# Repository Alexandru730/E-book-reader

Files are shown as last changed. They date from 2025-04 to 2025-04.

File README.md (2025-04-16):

# 📦 ESP32-C6 ePaper Project

Un proiect hardware ce integreaza un modul **ESP32-C6**, un **display e-Paper 7.5"**, alimentare prin **baterie Li-Ion** si conexiuni de testare prin **testpad-uri**. 

---

## 📊 Diagrama bloc

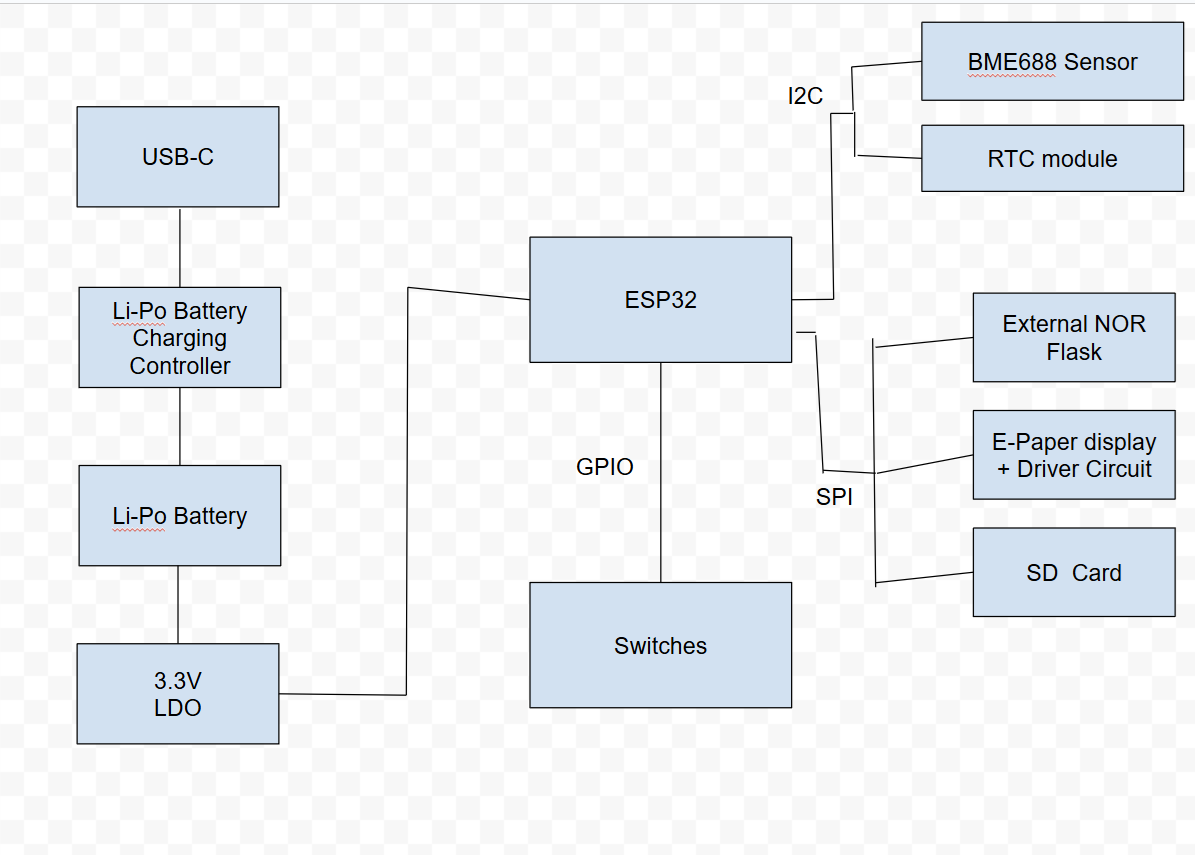
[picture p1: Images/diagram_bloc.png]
Diagrama Bloc


---

## 📦 BOM – Bill of Materials
| Componenta | Achizitie | Datasheet |
|---|---|---|
| PFMF.050.1 | [Cumpara](https://ro.mouser.com/ProductDetail/Schurter/PFMF.050.2?qs=1auRipcfynCums5v1iucSA%3D%3D) | [Datasheet](https://ro.mouser.com/datasheet/2/358/typ_PFMF-1275918.pdf) |
| USB4110-GF-A | [Cumpara](https://ro.mouser.com/ProductDetail/GCT/USB4110-GF-A?qs=KUoIvG%2F9IlYiZvIXQjyJeA%3D%3D) | [Datasheet](https://ro.mouser.com/datasheet/2/837/GCT_USB4110_Product_Drawing___20k_cycles-3455479.pdf) |
| USBLC6-2SC6Y | [Cumpara](https://ro.mouser.com/ProductDetail/STMicroelectronics/USBLC6-2SC6Y?qs=gNDSiZmRJS%2FOgDexvXkdow%3D%3D) | [Datasheet](https://ro.mouser.com/datasheet/2/389/usblc6_2sc6y-1852505.pdf) |
| SD0805S020S1R0 | [Cumpara](https://ro.mouser.com/ProductDetail/KYOCERA-AVX/SD0805S020S1R0?qs=jCA%252BPfw4LHbpkAoSnwrdjw%3D%3D) | [Datasheet](https://ro.mouser.com/datasheet/2/40/schottky-3165252.pdf) |
| DMG2305UX-7 | [Cumpara](https://ro.mouser.com/ProductDetail/Diodes-Incorporated/DMG2305UX-7?qs=L1DZKBg7t5F%2FNBHrjfxC%252Bg%3D%3D) | [Datasheet](https://www.diodes.com/assets/Datasheets/DMG2305UX.pdf) |
| XC6220A331MR-G | [Cumpara](https://ro.mouser.com/ProductDetail/Torex-Semiconductor/XC6220A331MR-G?qs=AsjdqWjXhJ8ZSWznL1J0gg%3D%3D) | [Datasheet](https://ro.mouser.com/datasheet/2/760/xc6220-3371556.pdf) |
| Condensator 100 uF TANT | [Cumpara](https://ro.mouser.com/ProductDetail/KYOCERA-AVX/TAJW107M010RNJ?qs=Wtp%252Bf%2FAeVqIH8v1VxV%252B1Rg%3D%3D) | [Datasheet](https://ro.mouser.com/datasheet/2/40/TAJ-3165264.pdf) |
| 112A-TAAR-R03_ATTEND | [Cumpara](https://www.digikey.ro/en/products/detail/attend-technology/112A-TAAR-R03/17633923) | [Datasheet](https://www.attend.com.tw/data/download/file/112A-TAAR-R03_Spec.pdf) |
| ESP32-C6-WROOM-1-N8 | [Cumpara](https://ro.mouser.com/ProductDetail/Espressif-Systems/ESP32-C6-WROOM-1-N8?qs=8Wlm6%252BaMh8ST02Gmwp74cw%3D%3D) | [Datasheet](https://ro.mouser.com/datasheet/2/891/Espressif_ESP32_C6_WROOM_1__Datasheet_V0_1_PRELIMI-3239987.pdf) |
| MCP73831 | [Cumpara](https://ro.mouser.com/ProductDetail/Microchip-Technology/MCP73831T-2ACI-OT?qs=yUQqVecv4qvbBQBGbHx0Mw%3D%3D) | [Datasheet](https://ro.mouser.com/datasheet/2/268/MCP73831_Family_Data_Sheet_DS20001984H-3441711.pdf) |
| CHG_LED | [Cumpara](https://store.comet.srl.ro/Catalogue/Product/40478/) | [Datasheet](https://www.snapeda.com/parts/KP-1608SURCK/Kingbright/datasheet/) |
| SI1308EDL-T1-GE3 | [Cumpara](https://ro.mouser.com/ProductDetail/Vishay-Semiconductors/SI1308EDL-T1-GE3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) | [Datasheet](https://www.vishay.com/doc?63399) |
| MBR0530 | [Cumpara](https://ro.mouser.com/ProductDetail/Micro-Commercial-Components-MCC/MBR0530-T?qs=9VyI4qLX4NTSXkb9ynzJnA%3D%3D) | [Datasheet](https://ro.mouser.com/datasheet/2/258/mcc_mbr0520~mbr0560sod123-1179695.pdf) |
| Bobina | [Cumpara](https://ro.mouser.com/ProductDetail/Wurth-Elektronik/744043680?qs=PGXP4M47uW6VkZq%252BkzjrHA%3D%3D) | [Datasheet](https://www.we-online.com/components/products/datasheet/744043680.pdf) |
| FH34SRJ-24S-0.5SH_99_ | [Cumpara](https://ro.mouser.com/ProductDetail/Hirose-Connector/FH34SRJ-24S-0.5SH99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) | [Datasheet](https://ro.mouser.com/datasheet/2/185/FH34SRJ_24S_0_5SH_99__CL0580_1255_6_99_2DDrawing_0-1615044.pdf) |
| BME688 | [Cumpara](https://ro.mouser.com/ProductDetail/Bosch-Sensortec/BME688?qs=IS%252B4QmGtzzqQoVDscqwx3A%3D%3D) | [Datasheet](https://ro.mouser.com/datasheet/2/783/bst_bme688_fl000-2307034.pdf) |
| BD5229G-TR | [Cumpara](https://ro.mouser.com/ProductDetail/ROHM-Semiconductor/BD5229G-TR?qs=4kLU8WoGk0vvnhrrYwdszw%3D%3D) | [Datasheet](https://fscdn.rohm.com/en/products/databook/datasheet/ic/power/voltage_detector/bd52xxg-e.pdf) |
| Switch | [Cumpara](https://ro.mouser.com/ProductDetail/CK/KMR221GULCLFS?qs=u2NJ%252B70r0goBXaNk7IrU0Q%3D%3D) | [Datasheet](https://www.ckswitches.com/media/1479/kmr2.pdf) |
| MAX17048G+T10 | [Cumpara](https://ro.mouser.com/ProductDetail/Analog-Devices-Maxim-Integrated/MAX17048G%2bT10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) | [Datasheet](https://ro.mouser.com/datasheet/2/609/MAX17048_MAX17049-3469099.pdf) |
| W25Q512JVEIQ | [Cumpara](https://ro.mouser.com/ProductDetail/Winbond/W25Q512JVEIQ?qs=l7cgNqFNU1jw6svr3at6tA%3D%3D) | [Datasheet](https://ro.mouser.com/datasheet/2/949/Winbond_W25Q512JV_Datasheet-3240039.pdf) |
| PGB1010603MR | [Cumpara](https://ro.mouser.com/ProductDetail/Littelfuse/PGB1010603MRHF?qs=KvZd0dN2Zg%2FuIq6icj%252BGKA%3D%3D) | [Datasheet](https://www.littelfuse.com/media?itemid=8a337998-d54d-466b-be4e-dc5bcd1f9321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) |
| QWIIC_RIGHT_ANGLE | [Cumpara](https://ro.mouser.com/ProductDetail/Analog-Devices-Maxim-Integrated/DS3231SN?qs=ffX8NcjNb2RmKAb9wAk9Ug%3D%3D) | [Datasheet](https://ro.mouser.com/datasheet/2/837/GCT_USB4110_Product_Drawing___20k_cycles-3455479.pdf) |
| DS3231SN# | [Cumpara](https://ro.mouser.com/ProductDetail/Analog-Devices-Maxim-Integrated/DS3231SN?qs=ffX8NcjNb2RmKAb9wAk9Ug%3D%3D) | [Datasheet](https://ro.mouser.com/datasheet/2/609/DS3231-3421123.pdf) |
| CPH3225A C10_SUPERCAP | [Cumpara](https://ro.mouser.com/ProductDetail/Seiko-Semiconductors/CPH3225A?qs=3etwrb1wR%252BhUOph6lAO7eg%3D%3D) | [Datasheet](https://ro.mouser.com/datasheet/2/360/Seiko_Instruments_MicroBattery_E_20230330_2024Jan_-3561061.pdf) |
| Condensator 100nF | [Cumpara](https://ro.mouser.com/ProductDetail/KYOCERA-AVX/06033G104ZAT2A?qs=NXubJDmysXJMPmHfVo6Z%252BA%3D%3D) | [Datasheet](https://ro.mouser.com/datasheet/2/40/KGM_Y5V-3223189.pdf) |
| Condensator 4.7uF | [Cumpara](https://ro.mouser.com/ProductDetail/KYOCERA-AVX/0402ZD475MAT2A?qs=NBFAU1oqP4W4U2PCPHI0sg%3D%3D) | [Datasheet](https://ro.mouser.com/datasheet/2/40/cx5r_KGM-3223198.pdf) |
| Condensator 10uF | [Cumpara](https://ro.mouser.com/ProductDetail/Samsung-Electro-Mechanics/CL10A106KQ8NNNL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) | [Datasheet](https://ro.mouser.com/datasheet/2/585/MLCC-1837944.pdf) |
| Condensator 1uF/50V | [Cumpara](https://ro.mouser.com/ProductDetail/KYOCERA-AVX/06035D105MAT2A?qs=k4kUdCzLgS5%252BURKe1SOIeQ%3D%3D) | [Datasheet](https://ro.mouser.com/datasheet/2/40/cx5r_KGM-3223198.pdf) |
| Rezistenta 10K | [Cumpara](https://ro.mouser.com/ProductDetail/Vishay-Beyschlag/MCS0402MD1002BE000?qs=17u8i%2FzlE8%2F9BrAaXkMk1w%3D%3D) | [Datasheet](https://www.vishay.com/doc?28952) |
| Rezistenta 200 | [Cumpara](https://ro.mouser.com/ProductDetail/Vishay-Beyschlag/MCS0402MD2000BE100?qs=3SvaY9RawMJNVte4F12%252BZQ%3D%3D) | [Datasheet](https://www.vishay.com/doc?28952) |
| Rezistenta 100K | [Cumpara](https://ro.mouser.com/ProductDetail/Vishay-Beyschlag/MCT0603PD1003DP500?qs=5aG0NVq1C4wWAn8Ei3OpZA%3D%3D) | [Datasheet](https://www.vishay.com/doc?28916) |
| Rezistenta 2.2 | [Cumpara](https://ro.mouser.com/ProductDetail/SEI-Stackpole/RMCF0402FT2R20?qs=IPgv5n7u5QbBgyl0jwhwsA%3D%3D) | [Datasheet](https://ro.mouser.com/datasheet/2/385/SEI_RMCF_RMCP-3077565.pdf) |
| Rezistenta 5K1 | [Cumpara](https://www.venkel.com/part/TFCR0603-16W-K-5690FT) | [Datasheet](https://ro.mouser.com/datasheet/2/385/SEI_RMCF_RMCP-3077565.pdf) |
| Rezistenta 2K | [Cumpara](https://ro.mouser.com/ProductDetail/Vishay-Beyschlag/MCS04020C2001FE000?qs=wTZ%2FFzl837YG0wIkZJJOwQ%3D%3D) | [Datasheet](https://www.vishay.com/doc?28705) |
| Rezistenta 0.47 | [Cumpara](https://ro.mouser.com/ProductDetail/SEI-Stackpole/CSR0402JKR470?qs=IPgv5n7u5QawIB6nBEt8wA%3D%3D) | [Datasheet](https://ro.mouser.com/datasheet/2/385/SEI_CSR_CSRN-3077593.pdf) |
| Rezistenta 15 | [Cumpara](https://ro.mouser.com/ProductDetail/YAGEO/RT0402FRE0715RL?qs=BXCcY9r%252B08DFFpLSkPOIqQ%3D%3D) | [Datasheet](https://ro.mouser.com/datasheet/2/447/PYu_RT_1_to_0_01_RoHS_L_15-3461507.pdf) |
                                                  |

---

## ⚙️ Functionalitate Hardware

- 🧠 **ESP32-C6**: procesor principal, WiFi si BLE
- 🖼️ **Display e-Paper 7.5”**: conectat prin interfata SPI
- 🔋 **Baterie Li-Ion 3.7V**: conectare directa la testpad-uri
- 🧪 **Testpad-uri**: pentru alimentare, masuratori si debugging
- 🧲 Toate GND-urile sunt conectate intr-un plan de masa dublu (top/bottom) cu **via stitching**

---

# Tabel Pini ESP32-C6 - Configuratie si Functii

| Nume | GPIO / Pin | Functie | Descriere |
|---|---|---|---|
| 3V3 | 3V3 | Sursa 3.3V | Asigura alimentarea necesara functionarii ESP32-C6 si componentelor logice |
| EN (Reset) | EN | Activare/Dezactivare microcontroler | Reset hardware prin semnal LOW |
| USB_D- | IO12 | Linie USB negativa | Parte din perechea diferentiala pentru USB 2.0 |
| USB_D+ | IO13 | Linie USB pozitiva | Parte din perechea diferentiala pentru USB 2.0 |
| Buton Boot | IO9 | Mod bootloader | Se conecteaza la GND pentru a initia programarea |
| Buton Change | IO15 | Mod operare | Comuta intre moduri definite in firmware |
| TX (UART) | GPIO16 (TXD0) | UART TX | Transmitere date seriale |
| RX (UART) | GPIO17 (RXD0) | UART RX | Receptie date seriale |
| SCK (SPI) | IO6 | SPI Clock | Ceas pentru comunicatia SPI |
| MOSI (SPI) | IO7 | SPI Master Out | Transmitere date SPI |
| MISO (SPI) | IO2 | SPI Master In | Receptie date SPI |
| FLASH_CS | IO11 | Chip Select NOR Flash | Activeaza memoria flash |
| EPD_CS | IO10 | Chip Select E-Paper | Activeaza ecranul E-Paper |
| EPD_DC | IO5 | Comanda/Date E-Paper | Diferentiaza comenzi vs date pentru E-Paper |
| EPD_RST | IO23 | Reset E-Paper | Reset hardware pentru E-Paper |
| EPD_BUSY | IO3 | Busy E-Paper | Semnalizeaza ca E-Paper este ocupat |
| SDA (I2C) | IO21 | I2C Data | Comunicatie cu RTC, BME688, etc. |
| SCL (I2C) | IO22 | I2C Clock | Ceas I2C |
| SS_SD | IO4 | Chip Select SD Card | Activeaza cardul SD |
| I2C_PW | IO19 | Power control senzori I2C | Activeaza/dezactiveaza alimentarea senzorilor I2C |
| EPD_3V3_C | IO20 | Alimentare 3.3V E-Paper | Sursa dedicata pentru E-Paper |
| 32KHZ | IO1 | Semnal 32kHz | Clock pentru RTC sau alte functii |
| INT_RTC | IO0 | Intrerupere RTC | Trezeste sistemul sau semnaleaza un eveniment RTC |
| RTC_RST | IO18 | Reset RTC | Permite resetarea manuala a ceasului RTC |

---

## 🖼️ Design Mecanic & 3D

- ✅ PCB proiectat si exportat 3D in Autodesk Fusion
- ✅ Model 3D complet pentru **baterie** si **display**, pe baza dimensiunilor din datasheet
- ✅ Integrare completa in **carcasa 3D** (asamblare in Fusion)
- ✅ Exploded view pentru randare si prezentare

---

## 🖼️ Randari

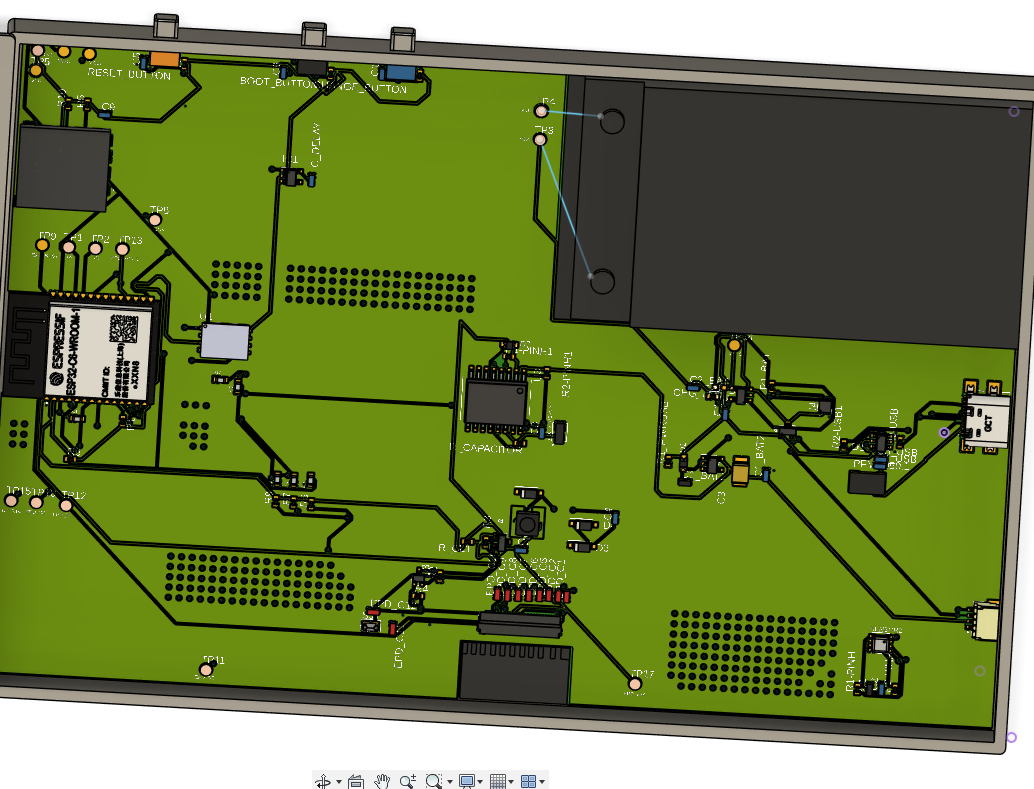
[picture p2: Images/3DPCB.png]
Randare 3D a placii
- ✅  
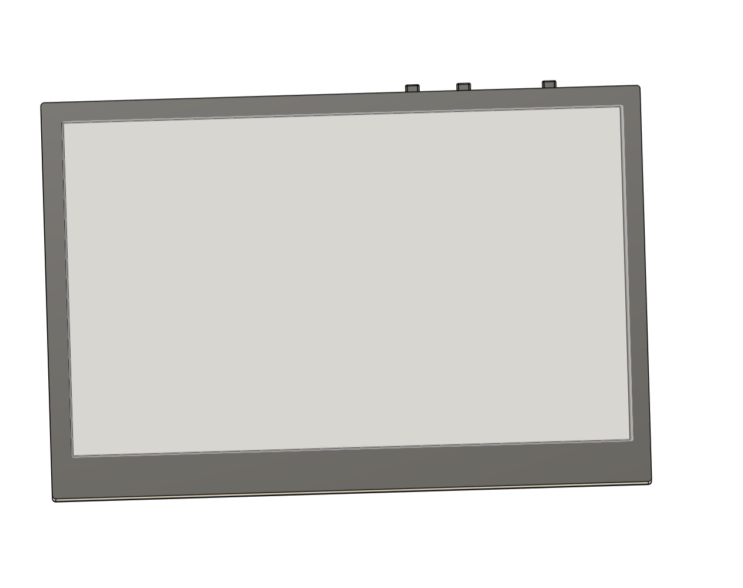
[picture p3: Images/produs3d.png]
Placa in carcasa
- ✅ 
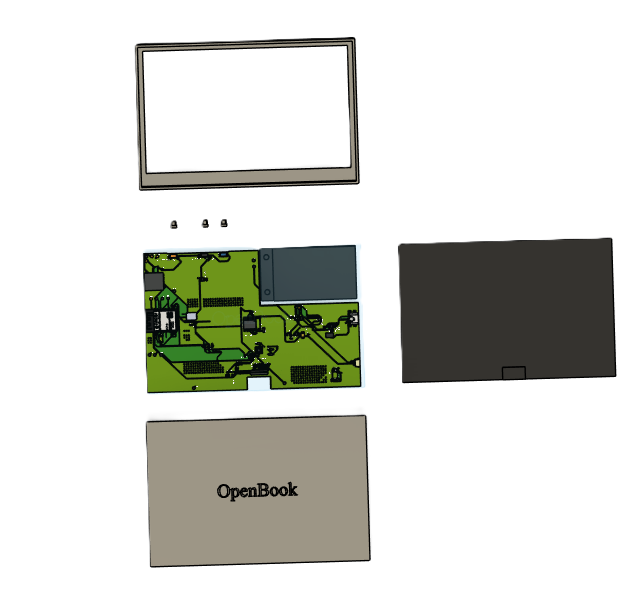
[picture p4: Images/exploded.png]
Vedere explodata
- ✅ 

---
# Vizualizare 3D Autodesk

Model 3D interactiv găzduit pe Autodesk Viewer.

[🔗 Modelul direct in Autodesk Viewer](https://stud33517.autodesk360.com/shares/public/SH30dd5QT870c25f12fc75d2ac08da186a19).1

## Etape de implementare:
 - Am inceput cu asamblarea pieselor in schematic din biblioteca data, apoi cu trecerea la placa pcb, decuparea placii, masuratori luate pentru amplasarea corecta a pieselor si pentru integrarea usoara a placii in carcasa data.
 - A urmat amplasarea pieselor, am facut traseele de putere manual cu grosimea de 0.3mm, iar apoi pentru celelate trasee am folosit autoroute, cu grosimea de 0.16mm, un singur vias pe un traseu de putere am avut pentru ca nu am mai avut cum sa il leg pe layer-ul top.
 - Am facut planul de masa pe bottom si pe top, am folosit via stitching.
 - Iar apoi am trecut la pcb in 3d, am incarcat toate piesele in 3d si am trecut la masuratorile pentru baterie si ecran.
 - Bateria am facut-o simpla cu doua iesiri legate la doua testpaduri, vbat si gnd.
 - Display-ul l-am realizat dupa masuratorile date din datasheet, i-am facut si acel conector care intra in spatiul liber din placuta la connector display

# Erori
1. Am avut doua erori pe care le-am aprobat in pcb("Copper Width"), dar ele aveau grosimea buna.
2. Am gresit ceva si m-am intors la o varianta anterioara a pcb ului si dupa nu a mai fost sincronizat cu schematicul si nu mi-a mai mers randarea in 3d a placii si am luat totul de la inceput.
3. Mi s-a sters o componenta, mai exact cea de langa reset button, label-ul de RESET si am vazut abia la finalul proiectului, daca incercam sa o inlocuiesc cu ce trebuia mi se dadea totul peste cap si trebuia sa o iau de la capat, aveam niste erori care nu ma mai lasau sa dau push to 3d la pcb si nu se vedeau componentele in 3D, ceva warning uri in schematic, care ziceau de fire ca nu erau legate bine, sau ca o anumita componenta avea 3 iesiri, dar ea avea doar una.

## License

This project is licensed under the Apache License 2.0 - see the [LICENSE](LICENSE) file for details.

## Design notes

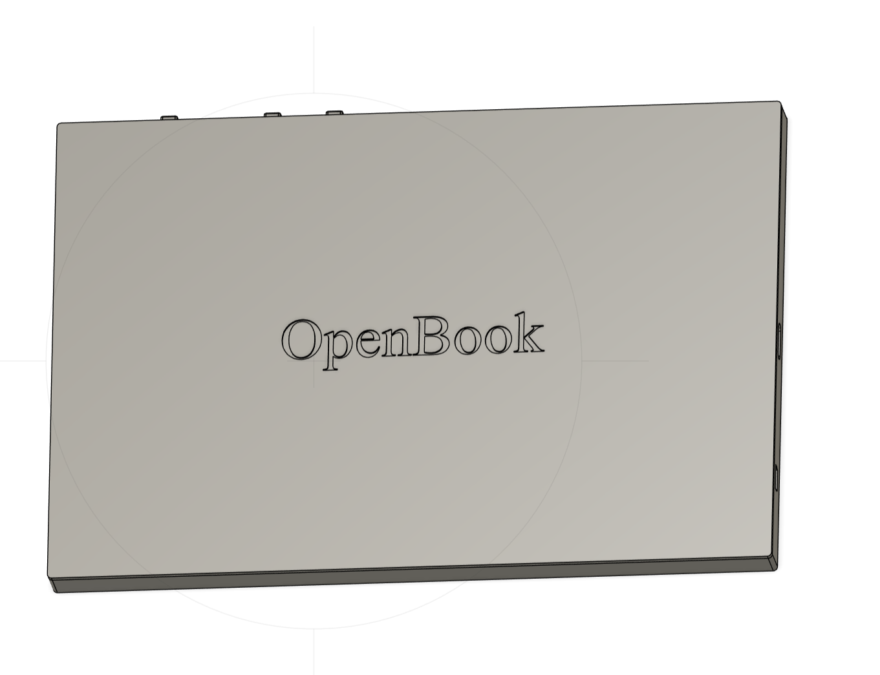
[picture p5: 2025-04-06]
Images/produs3d_1.png

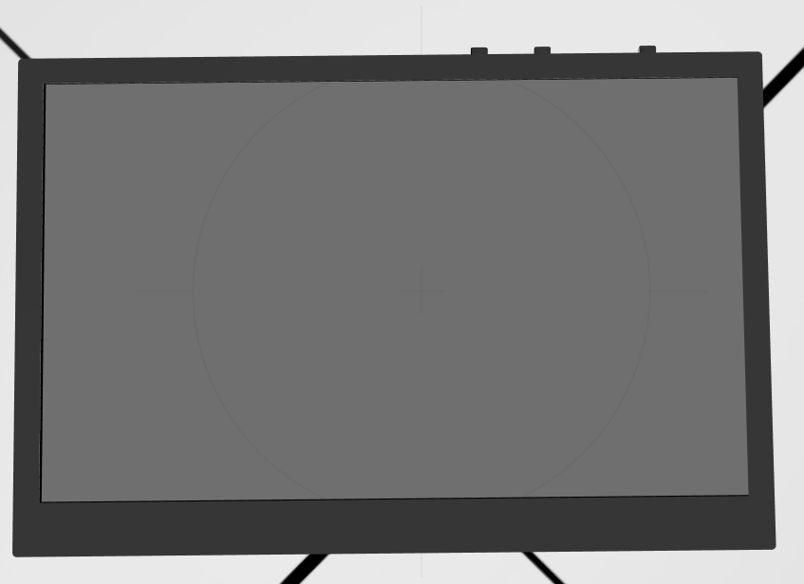
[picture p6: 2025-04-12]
Images/3D_product2.png

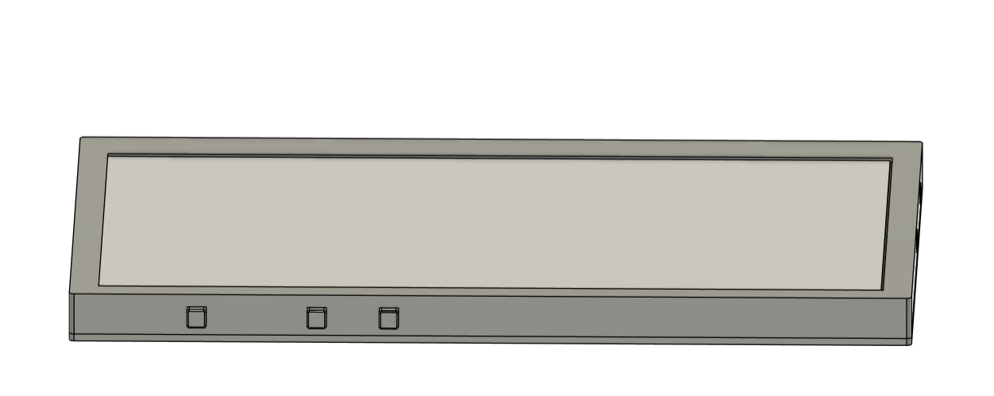
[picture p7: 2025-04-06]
Images/produs3d_2.png

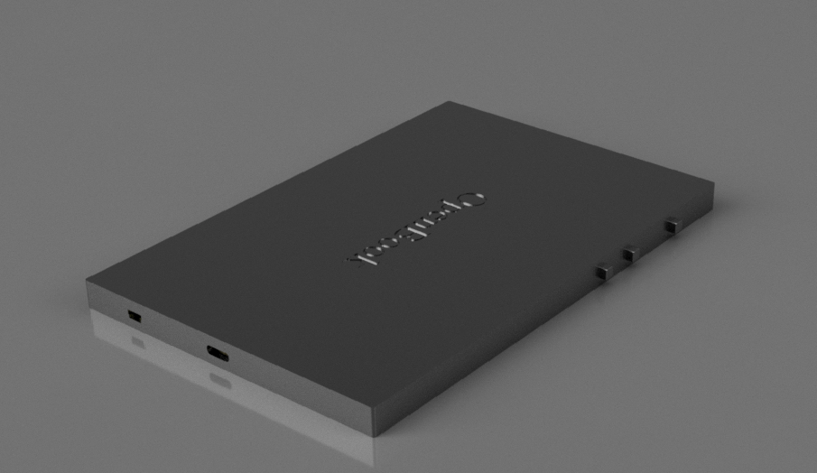
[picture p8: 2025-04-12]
Images/3D.png

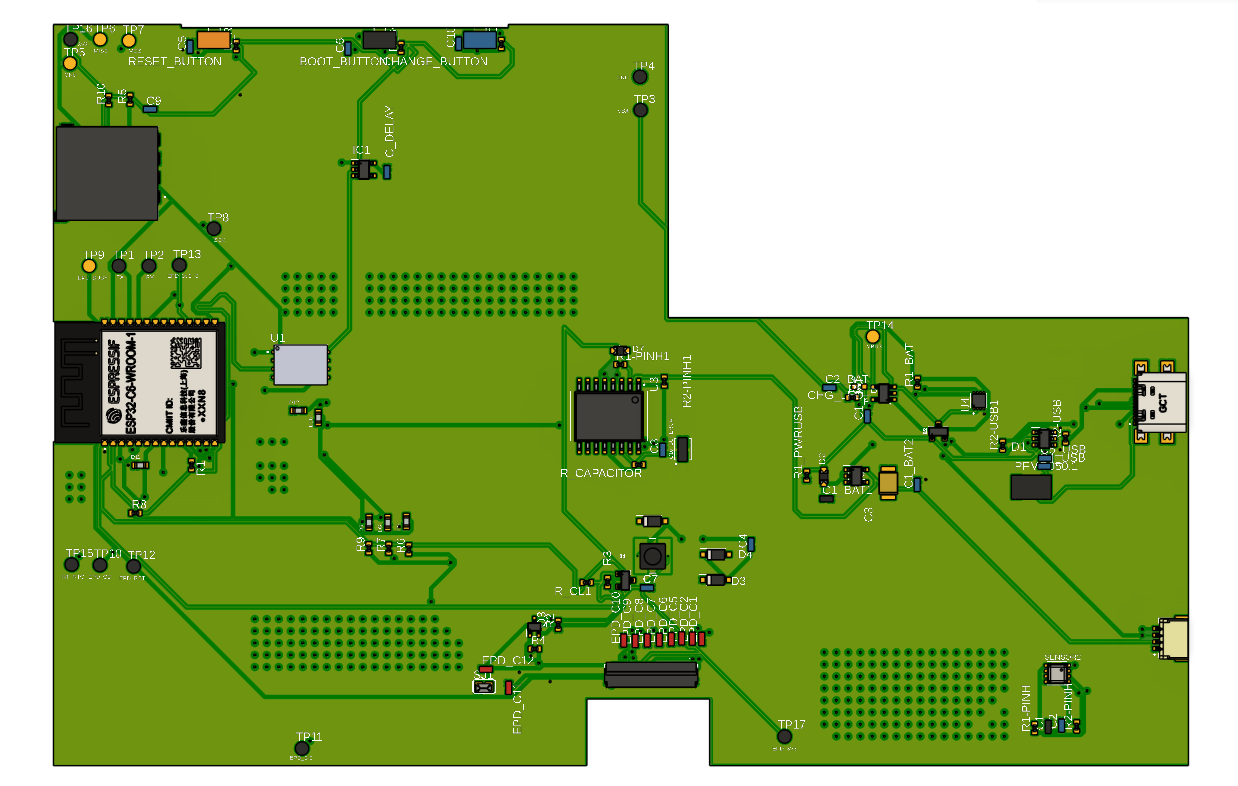
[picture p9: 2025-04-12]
Images/pcb3d.png

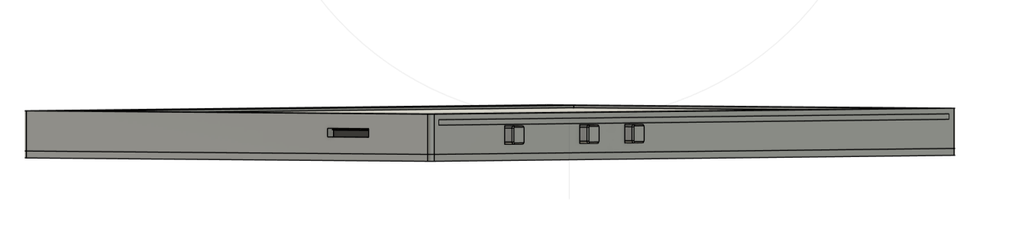
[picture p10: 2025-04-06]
Images/produs3d_4.png

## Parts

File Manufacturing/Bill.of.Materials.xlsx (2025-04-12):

Qty | Value | Device | Package | Parts | Description | ARROW_PART_NUMBER | ARROW_PRICE-STOCK | AVAILABILITY | CENTROID_NOT_SPECIFIED | CHECK_PRICES | COPYRIGHT | DATASHEET | DESCRIPTION | DIGIKEY_DESCRIPTION | DIGIKEY_PART_NUMBER | HEIGHT | LEAD_FREE | MANUFACTURER_NAME | MANUFACTURER_PART_NUMBER | MF | MFR_NAME | MOUSER_PART_NUMBER | MOUSER_PRICE-STOCK | MOUSER_TESTING_PART_NUMBER | MOUSER_TESTING_PRICE-STOCK | MP | MPN | PACKAGE | POPULARITY | PREFIX | PRICE | PROD_ID | PURCHASE-URL | ROHS | SNAPEDA_LINK | SPICEMODEL | SPICEPREFIX | TEMPERATURE_RANGE_HIGH | TEMPERATURE_RANGE_LOW | TP_SIGNAL_NAME | VALUE
1 |  | ADAFRUIT_LEDCHIP-LED0603 | ADAFRUIT_CHIP-LED0603 | CHG_LED | LED |  |  |  |  | https://www.snapeda.com/parts/7012X1/VCC/view-part/?ref=search&t=led
1 |  | SJ | SJ | SJ1 | SMD solder JUMPER |  |  |  |  | https://grabcad.com/library/solder-jumpers-1 (https://www.snapeda.com/parts/7012X1/VCC/view-part/?ref=search&t=led) |  |  |  |  |  |  |  |  |  |  |  |  |  |  |  |  |  |  | 3
1 | 0.47 | ESP32_WROVER_EAGLE-LTSPICE_RR0402 | ESP32_WROVER_EAGLE-LTSPICE_R0402 | R3 | RESISTOR, European symbol |  |  |  |  | https://componentsearchengine.com/part-view/R0402%201%25%20100%20K%20(RC0402FR-07100KL)/YAGEO |  |  |  |  |  |  |  |  |  |  |  |  |  |  |  |  |  |  |  |  |  |  |  |  |  | NONE | R
1 | 100K | ESP32_WROVER_EAGLE-LTSPICE_RR0402 | ESP32_WROVER_EAGLE-LTSPICE_R0402 | R1_PWRUSB | RESISTOR, European symbol |  |  |  |  | https://componentsearchengine.com/part-view/R0402%201%25%20100%20K%20(RC0402FR-07100KL)/YAGEO |  |  |  |  |  |  |  |  |  |  |  |  |  |  |  |  |  |  |  |  |  |  |  |  |  | NONE | R
8 | 100nF | EAGLE-LTSPICE_CC0402 | EAGLE-LTSPICE_C0402 | C1, C2, C4_USB, C6, C8, C9, C10, C_DELAY | CAPACITOR, European symbol |  |  |  |  | https://componentsearchengine.com/part-view/CC0402MRX5R5BB106/YAGEO |  |  |  |  |  |  |  |  |  |  |  |  |  |  |  |  |  |  |  |  |  |  |  |  |  | NONE | C
1 | 100uF | RCL_CPOL-EUCT3528 | RCL_CT3528 | C3 | POLARIZED CAPACITOR, European symbol |  |  |  |  | https://a360.co/4iZy6AA |  |  |  |  |  |  |  |  |  |  |  |  |  |  |  |  |  |  | 0 |  |  |  |  |  |  |  | C
16 | 10K | ESP32_WROVER_EAGLE-LTSPICE_RR0402 | ESP32_WROVER_EAGLE-LTSPICE_R0402 | R1, R1-PINH, R1_PINH1, R2-PINH, R2_PINH1, R4, R5, R6, R7, R8, R9, R10, R_BOOT, R_CHANGE, R_CL1, R_RESET | RESISTOR, European symbol |  |  |  |  | https://componentsearchengine.com/part-view/R0402%201%25%20100%20K%20(RC0402FR-07100KL)/YAGEO |  |  |  |  |  |  |  |  |  |  |  |  |  |  |  |  |  |  |  |  |  |  |  |  |  | NONE | R
1 | 10uF | EAGLE-LTSPICE_CC0402 | EAGLE-LTSPICE_C0402 | C7 | CAPACITOR, European symbol |  |  |  |  | https://componentsearchengine.com/part-view/CC0402MRX5R5BB106/YAGEO |  |  |  |  |  |  |  |  |  |  |  |  |  |  |  |  |  |  |  |  |  |  |  |  |  | NONE | C
1 | 112A-TAAR-R03_ATTEND | 112A-TAAR-R03_ATTEND | 112ATAARR03ATTEND | J4 | Micro SD Card Socket, Push-Push Type, Top Mount, SMT, H=1.83mm, 10u |  |  |  |  | https://www.tme.eu/en/details/mcc-sdmicro/card-connectors/attend/112a-taar-r03/ |  |  | Micro SD Card Socket | Push-Push Type | Top Mount | SMT | H=1.83mm | 10u |  |  | 1.9mm |  | ATTEND | 112A-TAAR-R03 ATTEND
1 | 15 | ESP32_WROVER_EAGLE-LTSPICE_RR0402 | ESP32_WROVER_EAGLE-LTSPICE_R0402 | R_CAPACITOR | RESISTOR, European symbol |  |  |  |  | https://componentsearchengine.com/part-view/R0402%201%25%20100%20K%20(RC0402FR-07100KL)/YAGEO |  |  |  |  |  |  |  |  |  |  |  |  |  |  |  |  |  |  |  |  |  |  |  |  |  | NONE | R
1 | 1uF | EAGLE-LTSPICE_CC0402 | EAGLE-LTSPICE_C0402 | C5 | CAPACITOR, European symbol |  |  |  |  | https://componentsearchengine.com/part-view/CC0402MRX5R5BB106/YAGEO |  |  |  |  |  |  |  |  |  |  |  |  |  |  |  |  |  |  |  |  |  |  |  |  |  | NONE | C
10 | 1uF/50V | EAGLE-LTSPICE_CC0402 | EAGLE-LTSPICE_C0402 | EPD_C1, EPD_C2, EPD_C5, EPD_C6, EPD_C7, EPD_C8, EPD_C9, EPD_C10, EPD_C11, EPD_C12 | CAPACITOR, European symbol |  |  |  |  | https://componentsearchengine.com/part-view/CC0402MRX5R5BB106/YAGEO |  |  |  |  |  |  |  |  |  |  |  |  |  |  |  |  |  |  |  |  |  |  |  |  |  | NONE | C
1 | 2.2 | ESP32_WROVER_EAGLE-LTSPICE_RR0402 | ESP32_WROVER_EAGLE-LTSPICE_R0402 | R2 | RESISTOR, European symbol |  |  |  |  | https://componentsearchengine.com/part-view/R0402%201%25%20100%20K%20(RC0402FR-07100KL)/YAGEO |  |  |  |  |  |  |  |  |  |  |  |  |  |  |  |  |  |  |  |  |  |  |  |  |  | NONE | R
1 | 200 | ESP32_WROVER_EAGLE-LTSPICE_RR0402 | ESP32_WROVER_EAGLE-LTSPICE_R0402 | R1_BAT | RESISTOR, European symbol |  |  |  |  | https://componentsearchengine.com/part-view/R0402%201%25%20100%20K%20(RC0402FR-07100KL)/YAGEO |  |  |  |  |  |  |  |  |  |  |  |  |  |  |  |  |  |  |  |  |  |  |  |  |  | NONE | R
2 | 20V/4.2A/52m?/1.4W | ESP32_WROVER_SPARKFUN-DISCRETESEMI_MOSFET_PCH-DMG2305UX-7 | ESP32_WROVER_SPARKFUN-DISCRETESEMI_SOT23-3 | Q1, Q2 | P-channel MOSFETs |  |  |  |  | https://www.snapeda.com/parts/DMG2305UX-7/Diodes%20Inc./view-part/?ref=search&t=DMG2305UX-7 |  |  |  |  |  |  |  |  |  |  |  |  |  |  |  |  |  |  |  |  |  | TRAN-14388 |  |  |  |  |  |  |  |  | 20V/4.2A/52m?/1.4W
1 | 2K | ESP32_WROVER_EAGLE-LTSPICE_RR0402 | ESP32_WROVER_EAGLE-LTSPICE_R0402 | R2_BAT | RESISTOR, European symbol |  |  |  |  | https://componentsearchengine.com/part-view/R0402%201%25%20100%20K%20(RC0402FR-07100KL)/YAGEO |  |  |  |  |  |  |  |  |  |  |  |  |  |  |  |  |  |  |  |  |  |  |  |  |  | NONE | R
4 | 4.7uF | EAGLE-LTSPICE_CC0402 | EAGLE-LTSPICE_C0402 | C1_BAT, C1_BAT2, C2_BAT, C5_USB | CAPACITOR, European symbol |  |  |  |  | https://componentsearchengine.com/part-view/CC0402MRX5R5BB106/YAGEO |  |  |  |  |  |  |  |  |  |  |  |  |  |  |  |  |  |  |  |  |  |  |  |  |  | NONE | C
1 | 4.7uF | ESP32_WROVER_EAGLE-LTSPICE_CC0402 | ESP32_WROVER_EAGLE-LTSPICE_C0402 | C1_BAT1 | CAPACITOR, European symbol |  |  |  |  | https://componentsearchengine.com/part-view/CC0402MRX5R5BB106/YAGEO |  |  |  |  |  |  |  |  |  |  |  |  |  |  |  |  |  |  |  |  |  |  |  |  |  | NONE | C
1 | 4.7uF/25V | EAGLE-LTSPICE_CC0402 | EAGLE-LTSPICE_C0402 | C4 | CAPACITOR, European symbol |  |  |  |  | https://componentsearchengine.com/part-view/CC0402MRX5R5BB106/YAGEO |  |  |  |  |  |  |  |  |  |  |  |  |  |  |  |  |  |  |  |  |  |  |  |  |  | NONE | C
1 | 5K1 | ESP32_WROVER_EAGLE-LTSPICE_RR0402 | ESP32_WROVER_EAGLE-LTSPICE_R0402 | R2-USB1 | RESISTOR, European symbol |  |  |  |  | https://componentsearchengine.com/part-view/R0402%201%25%20100%20K%20(RC0402FR-07100KL)/YAGEO |  |  |  |  |  |  |  |  |  |  |  |  |  |  |  |  |  |  |  |  |  |  |  |  |  | NONE | R
1 | 5k1 | ESP32_WROVER_EAGLE-LTSPICE_RR0402 | ESP32_WROVER_EAGLE-LTSPICE_R0402 | R2-USB | RESISTOR, European symbol |  |  |  |  | https://componentsearchengine.com/part-view/R0402%201%25%20100%20K%20(RC0402FR-07100KL)/YAGEO |  |  |  |  |  |  |  |  |  |  |  |  |  |  |  |  |  |  |  |  |  |  |  |  |  | NONE | R
1 | 68uH | aDAFRUIT_LEDCHIP-LED0603 | IND_4828-WE-TPC_WRE | L1 |  |  |  |  |  | https://componentsearchengine.com/part-view/744043680/W%C3%BCrth%20Elektronik | Copyright (C) 2024 Ultra Librarian. All rights reserved. |  |  |  |  |  |  |  | 744043680 |  | Wurth Electronics
1 | BD5229G-TR | BD5229G-TR | SOT95P280X125-5N | IC1 | Voltage Detector with Adjustable Delay Time: CMOS processes are utilized to develop high precision, low current consumption CMOS reset ICs that allow arbitrary setting of the delay time. The extensive lineup includes both Nch Open Drain and CMOS output types in a wide range of detection voltages (from 2.3V to 6.0V, in 0.1V steps), enabling selection of the ideal solution based on customer requirements. In addition, the entire series is of course both lead-free and RoHS-compliant. |  |  |  |  | https://componentsearchengine.com/part-view/BD5229G-TR/ROHM%20Semiconductor |  |  | Voltage Detector with Adjustable Delay Time: CMOS processes are utilized to develop high precision | low current consumption CMOS reset ICs that allow arbitrary setting of the delay time. The extensive lineup includes both Nch Open Drain and CMOS output types in a wide range of detection voltages (from 2.3V to 6.0V | in 0.1V steps) | enabling selection of the ideal solution based on customer requirements. In addition | the entire series is of course both lead-free and RoHS-compliant. |  |  | 1.25mm |  | ROHM Semiconductor | BD5229G-TR |  |  | 755-BD5229G-TR | https://www.mouser.co.uk/ProductDetail/ROHM-Semiconductor/BD5229G-TR?qs=4kLU8WoGk0vvnhrrYwdszw%3D%3D
1 | BME688 | ESP32_WROVER_BME680_BME680 | ESP32_WROVER_BME680_PSON80P300X300X100-8N | SENSOR2 | Integrated Environmental Unit |  |  | Unavailable |  | https://componentsearchengine.com/part-view/BME680/BOSCH |  |  | Integrated Environmental Unit |  |  |  |  |  |  | Bosch Sensortec |  |  |  |  |  | BME680 |  | LGA-8 Bosch Tools |  |  | None
3 | BUTTON_CUSYOMV1 | BUTTON_CUSYOMV1 | MYBUTTON | BOOT_BUTTON, CHANGE_BUTTON, RESET_BUTTON |  |  |  |  |  | https://industry.panasonic.com/global/en/products/control/switch/light-touch/number/evqpuj02k
1 | CPH3225A | CPH3225A | CAPCP3225X100N | C10_SUPERCAP | Cap 0.011F 3.3V 1210 Flat Check availability |  |  | Not in stock |  | https://www.snapeda.com/parts/CPH3225A/Seiko+Instruments/view-part/?ref=eda |  |  | 11 mF (EDLC) Supercapacitor 3.3 V 1210 (3225 Metric) - - |  |  |  |  |  |  | Seiko Instruments |  |  |  |  |  | CPH3225A |  | 1210 Seiko |  |  | None |  | https://www.snapeda.com/api/url_track_click_mouser/?unipart_id=562593&manufacturer=Seiko Instruments&part_name=CPH3225A&search_term=None |  | https://www.snapeda.com/parts/CPH3225A/Seiko+Instruments/view-part/?ref=snap
1 | DS3231SN# | DS3231SN# | SOIC127P1032X265-16N | U3 | Real Time Clock Serial 16-Pin SOIC W T/R Check availability |  |  | In Stock |  | https://www.snapeda.com/parts/DS3231SN%23/Analog+Devices/view-part/?ref=eda |  |  | Extremely Accurate I2C-Integrated RTC/TCXO/Crystal |  |  |  |  |  |  | Analog Devices |  |  |  |  |  | DS3231SN# |  | SOIC-16 Maxim |  |  | None |  | https://www.snapeda.com/api/url_track_click_mouser/?unipart_id=99048&manufacturer=Analog Devices&part_name=DS3231SN#&search_term=None |  | https://www.snapeda.com/parts/DS3231SN%23/Analog+Devices/view-part/?ref=snap
1 | ESP32-C6-WROOM-1-N8 | ESP32-C6-WROOM-1-N8 | XCVR_ESP32-C6-WROOM-1-N8 | U1 | Check availability |  |  | In Stock |  | https://www.snapeda.com/parts/ESP32-C6-WROOM-1-N8/Espressif+Systems/view-part/?ref=eda |  |  | Multiprotocol Modules ESP32-C6 module | Wi-Fi 6 in 2.4 GHz band | Bluetooth 5 | Zigbee 3.0 and Thread. ESP34-WROOM Compatible - ENGINEERING SAMPLE |  |  |  |  |  |  | Espressif Systems |  |  |  |  |  | ESP32-C6-WROOM-1-N8 |  | None |  |  | None |  |  |  | https://www.snapeda.com/parts/ESP32-C6-WROOM-1-N8/Espressif+Systems/view-part/?ref=snap
1 | ESP32C6_VARISTORCN1812 | ESP32C6_VARISTORCN1812 | ESP32C6_VARISTOR_CT/CN1812 | PFMF.050.1 | VARISTOR |  |  |  |  | https://componentsearchengine.com/part-view/PFMF.050.2/SCHURTER |  |  |  |  |  |  |  |  |  |  |  |  |  |  |  |  |  |  | 0
2 | ESP32_WROVER_AVX---SD0805S020S1R0_AVX_SD0805S020S1R0_0_0AVX_SD0805S020S1R0_0_0 | ESP32_WROVER_AVX---SD0805S020S1R0_AVX_SD0805S020S1R0_0_0AVX_SD0805S020S1R0_0_0 | ESP32_WROVER_AVX---SD0805S020S1R0_AVX_SD0805S020S1R0_0 | D2, D7 | Schottky Barrier Rectifier Diode |  |  |  | No | https://eu.mouser.com/ProductDetail/KYOCERA-AVX/SD0805S020S1R0?qs=jCA%252BPfw4LHbpkAoSnwrdjw%3D%3D |  | http://datasheets.avx.com/schottky.pdf |  | DIODE SCHOTTKY 20V 1A 0805 | 478-7800-1-ND |  | yes |  |  | AVX |  | 581-SD0805S020S1R0 |  |  |  |  |  | 0805 (2012 metric) |  | D |  |  |  | yes |  |  |  | +125°C | -55°C
1 | ESP32_WROVER_SPARKFUN-IC-POWER_MCP73831 | ESP32_WROVER_SPARKFUN-IC-POWER_MCP73831 | ESP32_WROVER_SPARKFUN-IC-POWER_SOT23-5 | MCP73831 | MCP73831T Li-Ion, Li-Pol Controller |  |  |  |  | https://componentsearchengine.com/part-view/MCP73831-2ACI%2FOT/Microchip |  |  |  |  |  |  |  |  |  |  |  |  |  |  |  |  |  |  |  |  |  | IC-09995
1 | FH34SRJ-24S-0.5SH_99_ | FH34SRJ-24S-0.5SH_99_ | FH34SRJ24S05SH99 | J1 | (0.50mm) Surface Mount, Right Angle |  |  |  |  | https://componentsearchengine.com/part-view/FH34SRJ-24S-0.5SH(99)/Hirose |  |  | 24 Position FFC | FPC Connector Contacts | (0.50mm) Surface Mount | Right Angle |  |  | 1.1mm |  | Hirose | FH34SRJ-24S-0.5SH(99) |  |  | 798-FH34SRJ24S05SH99 | https://www.mouser.co.uk/ProductDetail/Hirose-Connector/FH34SRJ-24S-0.5SH99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
1 | MAX17048G+T10 | MAX17048G+T10 | SON50P200X200X80-9N | U4 | Check availability |  |  | In Stock |  | https://www.snapeda.com/parts/MAX17048G+T10/Analog+Devices/view-part/?ref=eda |  |  | 3µA 1-Cell/2-Cell Fuel Gauge with ModelGauge |  |  |  |  |  |  | Analog Devices |  |  |  |  |  | MAX17048G+T10 |  | TDFN-8 Maxim |  |  | None |  | https://www.snapeda.com/api/url_track_click_mouser/?unipart_id=329239&manufacturer=Analog Devices&part_name=MAX17048G+T10&search_term=None |  | https://www.snapeda.com/parts/MAX17048G+T10/Analog+Devices/view-part/?ref=snap
3 | MBR0530 | MBR0530 | SOD3716X135N | D3, D4, D5 | ON SEMICONDUCTOR - MBR0530 - DIODE, SCHOTTKY, 0.5A, 30V, SOD-123 |  |  | In Stock |  | https://www.snapeda.com/parts/MBR0530/Onsemi/view-part/?ref=eda |  |  | Diode Schottky 30 V 500mA Surface Mount SOD-123 |  |  |  |  |  |  | ON Semiconductor |  |  |  |  |  | MBR0530 |  | SOD-123-2 ON Semiconductor |  |  | None |  | https://www.snapeda.com/api/url_track_click_mouser/?unipart_id=179458&manufacturer=ON Semiconductor&part_name=MBR0530&search_term=None |  | https://www.snapeda.com/parts/MBR0530/Onsemi/view-part/?ref=snap
6 | PGB1010603MR | PGB1010603MR | DIOC1608X36N | D6, D8, D9, D10, D11, D12 | Check availability |  |  | In Stock |  | https://www.snapeda.com/parts/PGB1010603MR/Littelfuse/view-part/?ref=eda |  |  | 150V (Typ) Clamp - Ipp Tvs Diode Surface Mount 0603 (1608 Metric) |  |  |  |  |  |  | Littelfuse Inc. |  |  |  |  |  | PGB1010603MR |  | 0603 Littelfuse Inc. |  |  | None |  | https://www.snapeda.com/api/url_track_click_mouser/?unipart_id=5659453&manufacturer=Littelfuse Inc.&part_name=PGB1010603MR&search_term=None |  | https://www.snapeda.com/parts/PGB1010603MR/Littelfuse/view-part/?ref=snap
1 | QWIIC_RIGHT_ANGLE | QWIIC_CONNECTORJS-1MM | JST04_1MM_RA | J3 | SparkFun I2C Standard Qwiic Connector |  |  |  |  | https://componentsearchengine.com/part-view/PRT-14417/SparkFun |  |  |  |  |  |  |  |  |  |  |  |  |  |  |  |  |  |  |  |  |  | CONN-13694 |  |  |  |  |  |  |  |  | QWIIC_RIGHT_ANGLE
1 | SAMACSYS_PARTS_USB4110-GF-A | SAMACSYS_PARTS_USB4110-GF-A | SAMACSYS_PARTS_USB4110GFA | J2 | CONN USB 2.0 TYPE-C R/A SMT |  |  |  |  | https://componentsearchengine.com/part-view/USB4110-GF-A/GCT%20(GLOBAL%20CONNECTOR%20TECHNOLOGY) |  |  | CONN USB 2.0 TYPE-C R/A SMT |  |  | 3.26mm |  | GCT (GLOBAL CONNECTOR TECHNOLOGY) | USB4110-GF-A |  |  | 640-USB4110-GF-A | https://www.mouser.co.uk/ProductDetail/GCT/USB4110-GF-A?qs=KUoIvG%2F9IlYiZvIXQjyJeA%3D%3D
1 | SI1308EDL-T1-GE3 | SI1308EDL-T1-GE3 | SOT65P210X110-3N | Q3 | MOSFET N-Ch 30V 1.5A TrenchFET SC70 Vishay Si1308EDL-T1-GE3 N-channel MOSFET Transistor, 1.5 A, 30 V, 3-Pin SC-70 |  |  | In Stock |  | https://www.snapeda.com/parts/SI1308EDL-T1-GE3/Vishay+Siliconix/view-part/?ref=eda |  |  | Si1308EDL-T1-GE3 N-channel MOSFET Transistor | 1.5 A | 30 V | 3-Pin SC-70 | Siliconix / Vishay SI1308EDL-T1-GE3 |  |  |  |  |  |  | Vishay Siliconix |  |  |  |  |  | SI1308EDL-T1-GE3 |  | SOT-323 Vishay Semiconductor |  |  | None |  | https://www.snapeda.com/api/url_track_click_mouser/?unipart_id=274603&manufacturer=Vishay Siliconix&part_name=SI1308EDL-T1-GE3&search_term=None |  | https://www.snapeda.com/parts/SI1308EDL-T1-GE3/Vishay+Siliconix/view-part/?ref=snap
17 | TPTP20R | TPTP20R | TP20R | TP1, TP2, TP3, TP4, TP5, TP6, TP7, TP8, TP9, TP10, TP11, TP12, TP13, TP14, TP15, TP16, TP17 | Test pad |  |  |  |  | SelfMade |  |  |  |  |  |  |  |  |  |  |  |  |  |  |  |  |  |  | 2
1 | USBLC6-2SC6Y | USBLC6-2SC6Y | SOT95P280X145-6N | D1 | Low Cap. ESD Protection Auto SOT-23-6 STMicroelectronics USBLC6-2SC6Y, Dual Uni-Directional TVS Diode Array, 6-Pin SOT-23 |  |  | In Stock |  | https://www.snapeda.com/parts/USBLC6-2SC6Y/STMicroelectronics/view-part/?ref=eda |  |  | 17V Clamp 5A (8/20µs) Ipp Tvs Diode Surface Mount SOT-23-6 |  |  |  |  |  |  | STMicroelectronics |  |  |  |  |  | USBLC6-2SC6Y |  | SOT-23-6 STMicroelectronics |  |  | None |  |  |  | https://www.snapeda.com/parts/USBLC6-2SC6Y/STMicroelectronics/view-part/?ref=snap
1 | W25Q512JVEIQ | W25Q512JVEIQ | SON127P600X800X80-9N | U2 | Check availability |  |  | In Stock |  | https://www.snapeda.com/parts/W25Q512JVEIQ/Winbond+Electronics/view-part/?ref=eda |  |  | FLASH - NOR Memory IC 512Mb (64M x 8) SPI - Quad I/O 133 MHz 8-WSON (8x6) |  |  |  |  |  |  | Winbond Electronics |  |  |  |  |  | W25Q512JVEIQ |  | Package |  |  | None |  |  |  | https://www.snapeda.com/parts/W25Q512JVEIQ/Winbond+Electronics/view-part/?ref=snap
1 | XC6220A331MR-G | XC6220A331MR-G | SOT95P280X120-5N | IC4 | LDO Voltage Regulators |  |  |  |  | https://componentsearchengine.com/part-view/XC6220A331MR-G/Torex |  |  | LDO Voltage Regulators |  |  | 1.2mm |  | Torex | XC6220A331MR-G |  |  | 865-XC6220A331MR-G | https://www.mouser.co.uk/ProductDetail/Torex-Semiconductor/XC6220A331MR-G?qs=AsjdqWjXhJ8ZSWznL1J0gg%3D%3D

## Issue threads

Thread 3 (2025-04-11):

pcb - test pad-uri

Edis9955, 2025-04-11:
11.Test pad-urile vor fi clar marcate în silkscreen cu numele semnalelor pe care le poartă (de ex. MISO, MOSI, Rx, GND, etc.).

unrelated silkscreenul e  bun.

Closed 2025-04-12.

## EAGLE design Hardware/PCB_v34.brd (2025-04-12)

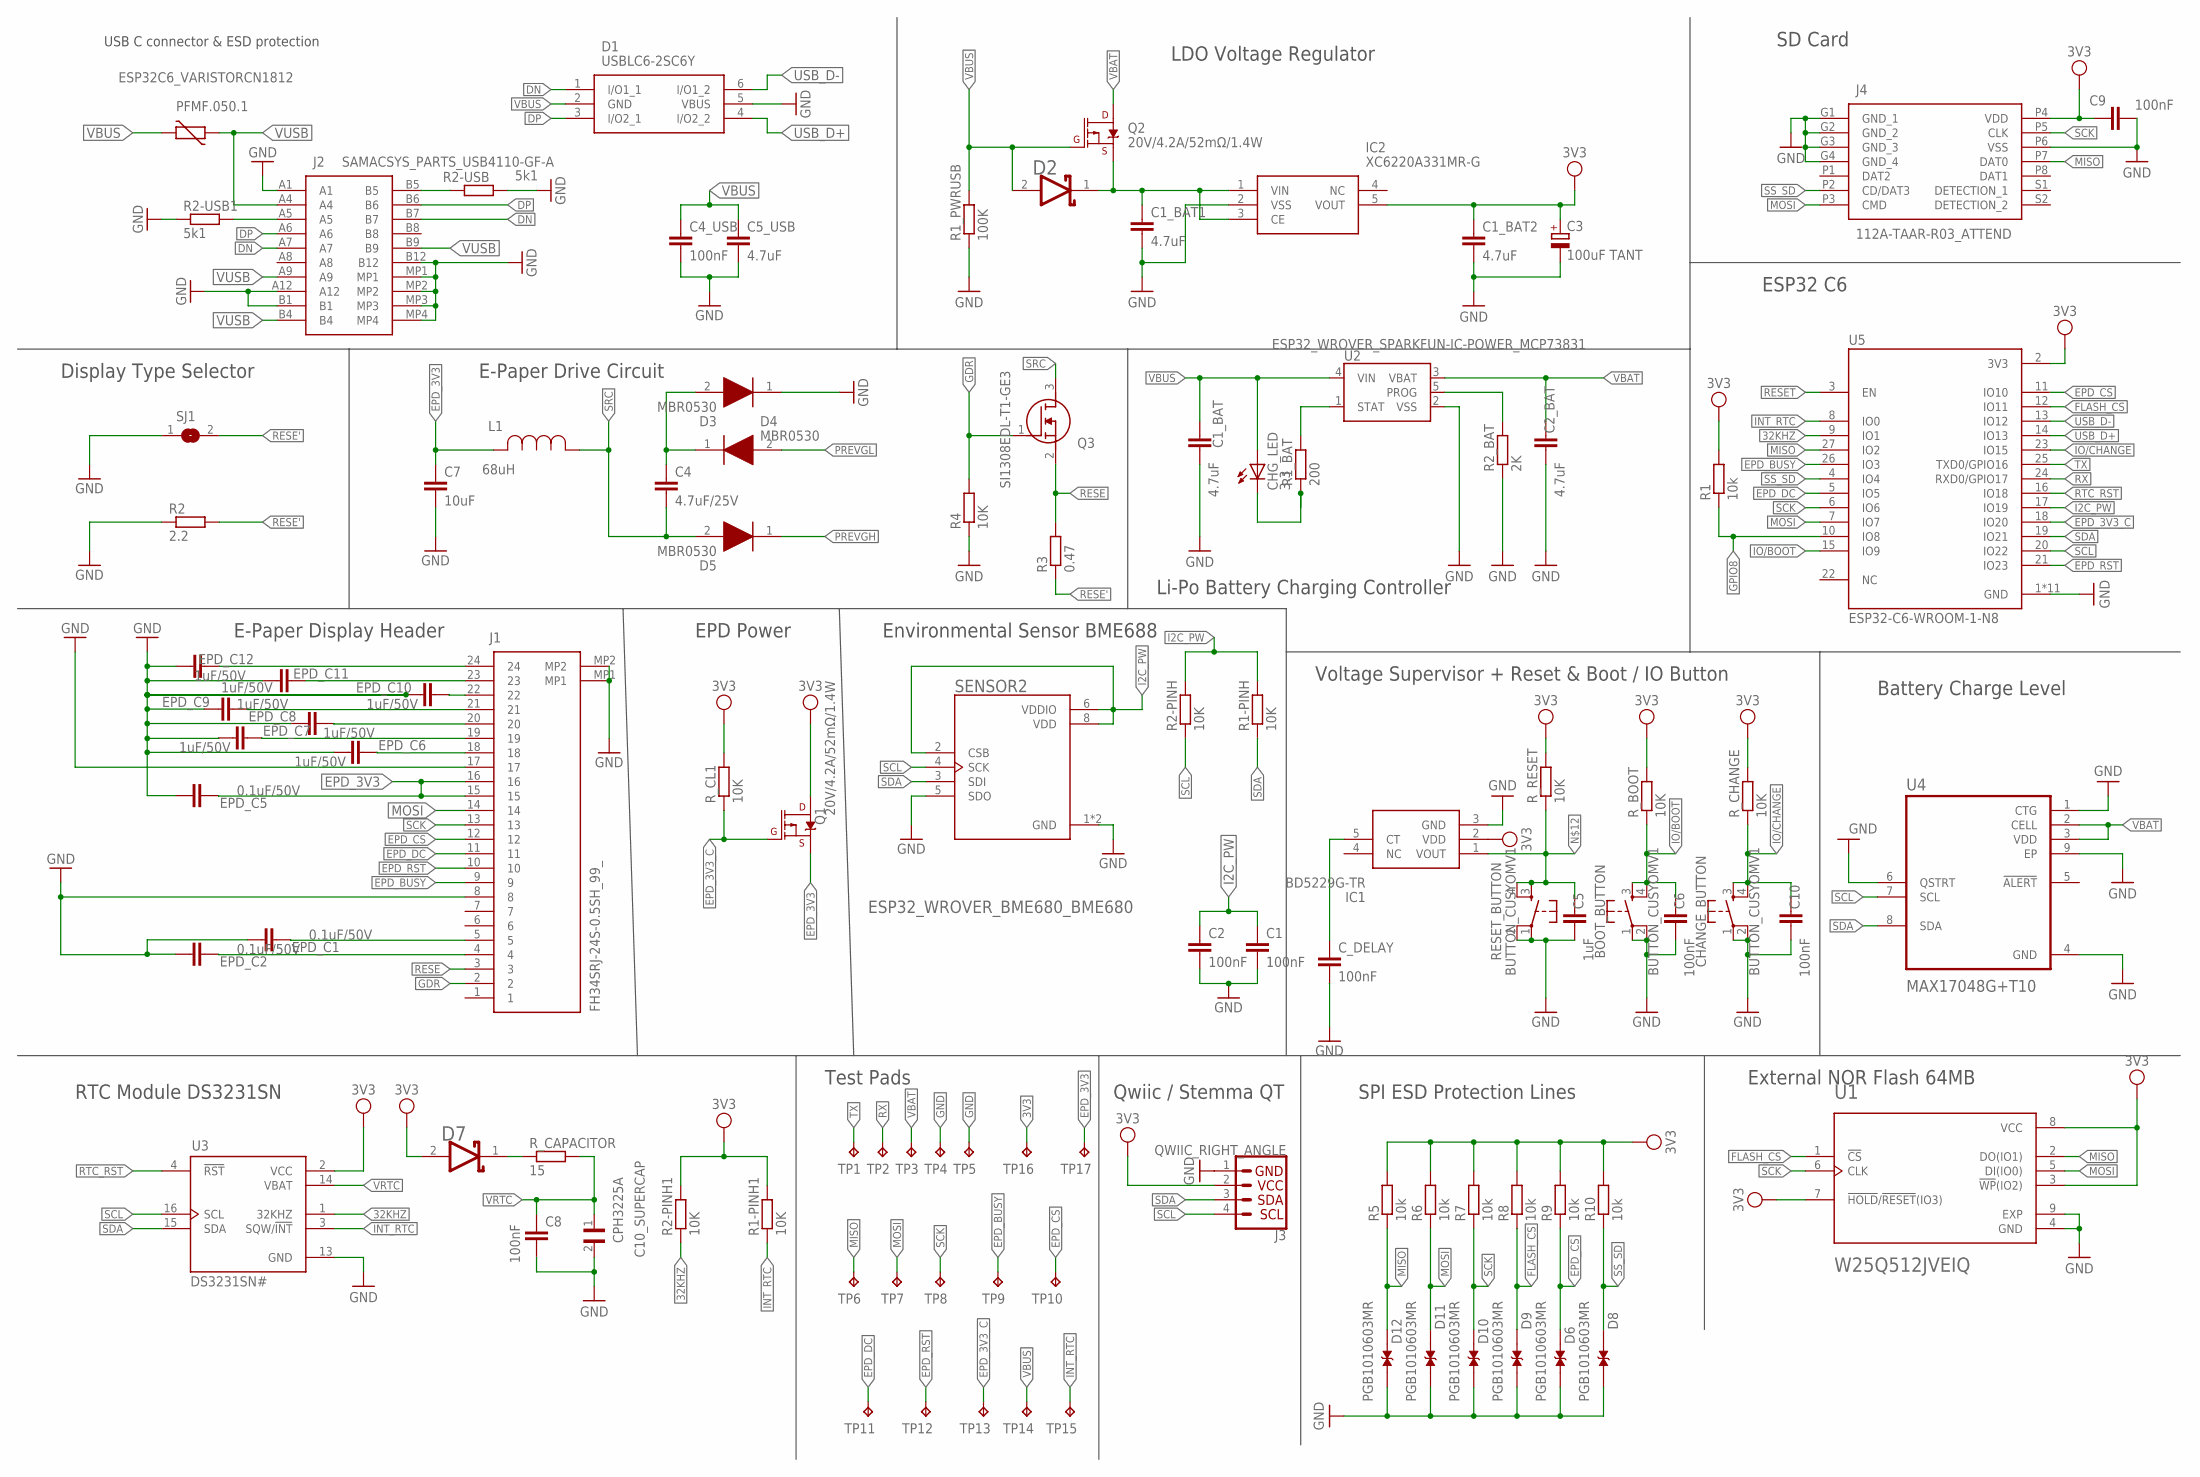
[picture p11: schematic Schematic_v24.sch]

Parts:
BOOT_BUTTON: BUTTON_CUSYOMV1; MYBUTTON
C1, C2, C4_USB, C6, C8, C9, C10: 100nF; ESP32_WROVER_EAGLE-LTSPICE_C0402
C1_BAT, C2_BAT, C5_USB: 4.7uF; ESP32_WROVER_EAGLE-LTSPICE_C0402
C1_BAT1, C1_BAT2: 4.7uF; EAGLE-LTSPICE_C0402
C3: 100uF TANT; RCL_CT3528
C4: 4.7uF/25V; ESP32_WROVER_EAGLE-LTSPICE_C0402
C5: 1uF; ESP32_WROVER_EAGLE-LTSPICE_C0402
C7: 10uF; ESP32_WROVER_EAGLE-LTSPICE_C0402
C10_SUPERCAP: CPH3225A; CAPCP3225X100N
CHANGE_BUTTON: BUTTON_CUSYOMV1; MYBUTTON
CHG_LED: 3.3; ADAFRUIT_CHIP-LED0603
C_DELAY: 100nF; ESP32_WROVER_EAGLE-LTSPICE_C0402
D1: USBLC6-2SC6Y; SOT95P280X145-6N
D2, D7: ESP32_WROVER_AVX---SD0805S020S1R0_AVX_SD0805S020S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; ESP32_WROVER_AVX---SD0805S020S1R0_AVX_SD0805S020S1R0_0
D3, D4, D5: MBR0530; SOD3716X135N
D6, D8, D9, D10, D11, D12: PGB1010603MR; DIOC1608X36N
EPD_C1, EPD_C2, EPD_C5: 0.1uF/50V; ESP32_WROVER_EAGLE-LTSPICE_C0402
EPD_C6, EPD_C7, EPD_C8, EPD_C9, EPD_C10, EPD_C11, EPD_C12: 1uF/50V; ESP32_WROVER_EAGLE-LTSPICE_C0402
IC1: BD5229G-TR; SOT95P280X125-5N
IC2: XC6220A331MR-G; SOT95P280X120-5N
J1: FH34SRJ-24S-0.5SH_99_; FH34SRJ24S05SH99
J2: SAMACSYS_PARTS_USB4110-GF-A; SAMACSYS_PARTS_USB4110GFA
J3: QWIIC_RIGHT_ANGLE; JST04_1MM_RA
J4: 112A-TAAR-R03_ATTEND; 112ATAARR03ATTEND
L1: 68uH; IND_4828-WE-TPC_WRE
PFMF.050.1: ESP32C6_VARISTORCN1812; ESP32C6_VARISTOR_CT/CN1812
Q1, Q2: 20V/4.2A/52mΩ/1.4W; ESP32_WROVER_SPARKFUN-DISCRETESEMI_SOT23-3
Q3: SI1308EDL-T1-GE3; SOT65P210X110-3N
R1, R5, R6, R7, R8, R9, R10: 10k; ESP32_WROVER_EAGLE-LTSPICE_R0402
R1-PINH, R1-PINH1, R2-PINH, R2-PINH1, R4: 10K; ESP32_WROVER_EAGLE-LTSPICE_R0402
R1_BAT: 200; ESP32_WROVER_EAGLE-LTSPICE_R0402
R1_PWRUSB: 100K; ESP32_WROVER_EAGLE-LTSPICE_R0402
R2: 2.2; ESP32_WROVER_EAGLE-LTSPICE_R0402
R2-USB, R2-USB1: 5k1; ESP32_WROVER_EAGLE-LTSPICE_R0402
R2_BAT: 2K; ESP32_WROVER_EAGLE-LTSPICE_R0402
R3: 0.47; ESP32_WROVER_EAGLE-LTSPICE_R0402
RESET_BUTTON: BUTTON_CUSYOMV1; MYBUTTON
R_BOOT: 10K; ESP32_WROVER_EAGLE-LTSPICE_R0402
R_CAPACITOR: 15; ESP32_WROVER_EAGLE-LTSPICE_R0402
R_CHANGE: 10K; ESP32_WROVER_EAGLE-LTSPICE_R0402
R_CL1: 10K; ESP32_WROVER_EAGLE-LTSPICE_R0402
R_RESET: 10K; ESP32_WROVER_EAGLE-LTSPICE_R0402
SENSOR2: ESP32_WROVER_BME680_BME680; ESP32_WROVER_BME680_PSON80P300X300X100-8N
SJ1: SJ
TP1, TP2, TP3, TP4, TP5, TP6, TP7, TP8, TP9, TP10, TP11, TP12, TP13, TP14, TP15, TP16, TP17: TPTP20R; TP20R
U1: W25Q512JVEIQ; SON127P600X800X80-9N
U2: ESP32_WROVER_SPARKFUN-IC-POWER_MCP73831; ESP32_WROVER_SPARKFUN-IC-POWER_SOT23-5
U3: DS3231SN#; SOIC127P1032X265-16N
U4: MAX17048G+T10; SON50P200X200X80-9N
U5: ESP32-C6-WROOM-1-N8; XCVR_ESP32-C6-WROOM-1-N8

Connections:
3V3: C1_BAT2.1, C3.+, C9.1, D7.2 (ANODE), IC1.2 (VDD), IC2.5 (VOUT), J3.2, J4.P4 (VDD), Q1.3 (D), R1.2, R1-PINH1.2, R2-PINH1.2, R5.2, R6.2, R7.2, R8.2, R9.2, R10.2, R_BOOT.2, R_CHANGE.2, R_CL1.2, R_RESET.2, TP16.TP, U1.3 (!WP!(IO2)), U1.7 (!HOLD!/!RESET!(IO3)), U1.8 (VCC), U3.2 (VCC), U5.2 (3V3)
32KHZ: R2-PINH1.1, U3.1 (32KHZ), U5.9 (IO1)
DN: D1.1 (I/O1_1), J2.A7, J2.B7
DP: D1.3 (I/O2_1), J2.A6, J2.B6
EPD_3V3: C7.1, EPD_C5.2, J1.15, J1.16, L1.2, Q1.2 (S), TP17.TP
EPD_3V3_C: Q1.1 (G), R_CL1.1, TP13.TP, U5.18 (IO20)
EPD_BUSY: J1.9, TP9.TP, U5.26 (IO3)
EPD_CS: D6.2, J1.12, R9.1, TP10.TP, U5.11 (IO10)
EPD_DC: J1.11, TP11.TP, U5.5 (IO5)
EPD_RST: J1.10, TP12.TP, U5.21 (IO23)
FLASH_CS: D9.2, R8.1, U1.1 (!CS), U5.12 (IO11)
GDR: J1.2, Q3.1 (G), R4.2
GND: BOOT_BUTTON.1, BOOT_BUTTON.2, C1.2, C1_BAT.2, C1_BAT1.2, C1_BAT2.2, C2.2, C2_BAT.2, C3.-, C4_USB.2, C5.2, C5_USB.2, C6.2, C7.2, C8.2, C9.2, C10.2, C10_SUPERCAP.2, CHANGE_BUTTON.1, CHANGE_BUTTON.2, C_DELAY.2, D1.5 (VBUS), D3.1 (K), D6.1, D8.1, D9.1, D10.1, D11.1, D12.1, EPD_C1.1, EPD_C2.1, EPD_C5.1, EPD_C6.1, EPD_C7.1, EPD_C8.1, EPD_C9.1, EPD_C10.1, EPD_C11.1, EPD_C12.1, IC1.3 (GND), IC2.2 (VSS), J1.8, J1.17, J1.MP1, J1.MP2, J2.A1, J2.A12, J2.B1, J2.B12, J2.MP1, J2.MP2, J2.MP3, J2.MP4, J3.1, J4.G1 (GND_1), J4.G2 (GND_2), J4.G3 (GND_3), J4.G4 (GND_4), J4.P6 (VSS), R1_PWRUSB.1, R2.1, R2-USB.2, R2-USB1.1, R2_BAT.1, R4.1, RESET_BUTTON.1, RESET_BUTTON.2, SENSOR2.1 (GND), SENSOR2.5 (SDO), SENSOR2.7 (GND), SJ1.1, TP4.TP, TP5.TP, U1.4 (GND), U1.9 (EXP), U2.2 (VSS), U3.13 (GND), U4.1 (CTG), U4.4 (GND), U4.6 (QSTRT), U4.9 (EP), U5.1 (GND), U5.28 (GND), U5.29_1 (GND), U5.29_2 (GND), U5.29_3 (GND), U5.29_4 (GND), U5.29_5 (GND), U5.29_6 (GND), U5.29_7 (GND), U5.29_8 (GND), U5.29_9 (GND)
GPIO8: R1.1, U5.10 (IO8)
I2C_PW: C1.1, C2.1, R1-PINH.2, R2-PINH.2, SENSOR2.2 (CSB), SENSOR2.6 (VDDIO), SENSOR2.8 (VDD), U5.17 (IO19)
INT_RTC: R1-PINH1.1, TP15.TP, U3.3 (SQW/!INT), U5.8 (IO0)
IO/BOOT: BOOT_BUTTON.3, BOOT_BUTTON.4, C6.1, R_BOOT.1, U5.15 (IO9)
IO/CHANGE: C10.1, CHANGE_BUTTON.3, CHANGE_BUTTON.4, R_CHANGE.1, U5.23 (IO15)
MISO: D12.2, J4.P7 (DAT0), R5.1, TP6.TP, U1.2 (DO(IO1)), U5.27 (IO2)
MOSI: D11.2, J1.14, J4.P3 (CMD), R6.1, TP7.TP, U1.5 (DI(IO0)), U5.7 (IO7)
unnamed: J2.B5, R2-USB.1
unnamed: D7.1 (CATHODE), R_CAPACITOR.1
unnamed: J2.A5, R2-USB1.2
unnamed: EPD_C11.2, J1.23
unnamed: EPD_C10.2, J1.22
unnamed: EPD_C9.2, J1.21
unnamed: C4.1, D3.2 (A), D4.1 (K)
unnamed: EPD_C8.2, J1.20
unnamed: EPD_C7.2, J1.19
unnamed: EPD_C6.2, J1.18
unnamed: C_DELAY.1, IC1.5 (CT)
unnamed: R1_BAT.2, U2.1 (STAT)
unnamed: CHG_LED.C, R1_BAT.1
unnamed: C1_BAT1.1, D2.1 (CATHODE), IC2.1 (VIN), IC2.3 (CE), Q2.2 (S)
unnamed: R2_BAT.2, U2.5 (PROG)
unnamed: EPD_C1.2, J1.5
unnamed: EPD_C2.2, J1.4
unnamed: EPD_C12.2, J1.24
PREVGH: D5.1 (K)
PREVGL: D4.2 (A)
RESE: J1.3, Q3.2 (S), R3.2
RESE': R2.2, R3.1, SJ1.2
RTC_RST: U3.4 (!RST), U5.16 (IO18)
RX: TP2.TP, U5.24 (RXD0/GPIO17)
SCK: D10.2, J1.13, J4.P5 (CLK), R7.1, TP8.TP, U1.6 (CLK), U5.6 (IO6)
SCL: J3.4, R2-PINH.1, SENSOR2.4 (SCK), U3.16 (SCL), U4.7 (SCL), U5.20 (IO22)
SDA: J3.3, R1-PINH.1, SENSOR2.3 (SDI), U3.15 (SDA), U4.8 (SDA), U5.19 (IO21)
SRC: C4.2, D5.2 (A), L1.1, Q3.3 (D)
SS_SD: D8.2, J4.P2 (CD/DAT3), R10.1, U5.4 (IO4)
TX: TP1.TP, U5.25 (TXD0/GPIO16)
USB_D+: D1.4 (I/O2_2), U5.14 (IO13)
USB_D-: D1.6 (I/O1_2), U5.13 (IO12)
VBAT: C2_BAT.1, Q2.3 (D), TP3.TP, U2.3 (VBAT), U4.2 (CELL), U4.3 (VDD)
VBUS: C1_BAT.1, C4_USB.1, C5_USB.1, CHG_LED.A, D1.2 (GND), D2.2 (ANODE), PFMF.050.1.2, Q2.1 (G), R1_PWRUSB.2, TP14.TP, U2.4 (VIN)
VRTC: C8.1, C10_SUPERCAP.1, R_CAPACITOR.2, U3.14 (VBAT)
VUSB: J2.A4, J2.A9, J2.B4, J2.B9, PFMF.050.1.1

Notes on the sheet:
USB C connector & ESD protection
SD Card
ESP32 C6
LDO Voltage Regulator
Display Type Selector
E-Paper Drive Circuit
E-Paper Display Header
EPD Power
Environmental Sensor BME688
Voltage Supervisor + Reset & Boot / IO Button
Battery Charge Level
External NOR Flash 64MB
SPI ESD Protection Lines
Qwiic / Stemma QT
Test Pads
RTC Module DS3231SN
Li-Po Battery Charging Controller

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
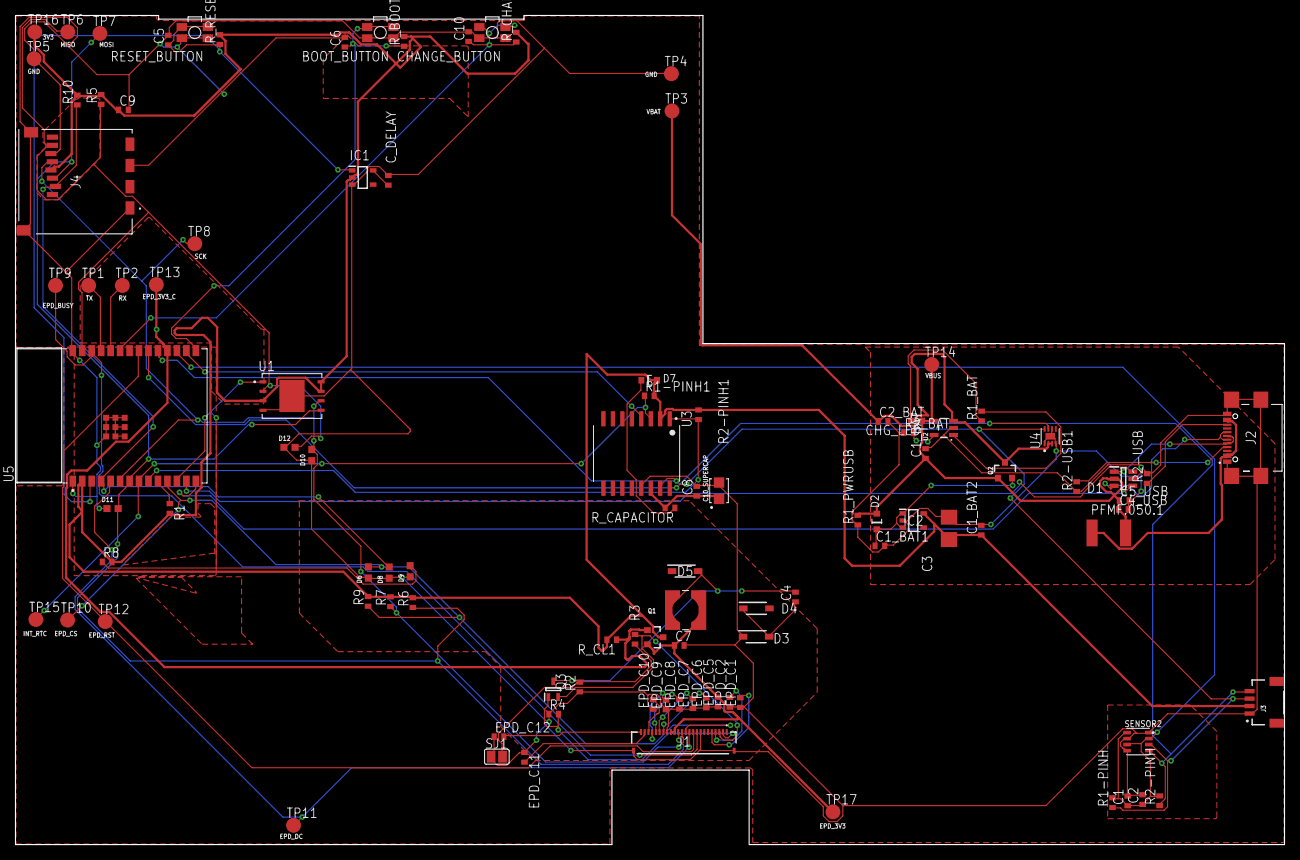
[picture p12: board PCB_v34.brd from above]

Board: 2 copper layers, 170.2 x 111.2 mm, 103 parts (0 on the bottom side), 55 nets.

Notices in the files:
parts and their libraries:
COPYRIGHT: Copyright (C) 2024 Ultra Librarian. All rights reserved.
